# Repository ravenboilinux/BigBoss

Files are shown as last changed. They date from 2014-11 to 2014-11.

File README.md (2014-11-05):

BigBoss
=======
First regulated box mode 

Goals
=====
1. selectable wattage in .1 steps up 100W
2. handles max 100W between the atty ranges .5 ohms to 2 ohms
3. uses 2 18650 batteries
4. charges the batteries by USB
5. has LCD display
6. LCD displays
  * selected wattage to the nearest .1 Wattage
  * battery power remaining
    - using a battery icon, with 4 section.
  * voltage coming out the DC-DC convert to the nearest .01 V
  * atty resistance to the nearest .1 Ohms
7. selected wattage is saved when there is no power to device
8. two button for wattage selection(up/down)
9. master button for turn off the device
10. fire button 
11. has reverse polority protection

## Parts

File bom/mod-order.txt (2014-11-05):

Order list for C:/Users/Mike/Documents/eagle/120WMod/mod.sch
Exported from EAGLE with DesignLink

Quantity	Value	Package	Order code	Manufacturer	Manuf. Code	Availability	Price (from)	Description
1		C0805	68R0289		RC0805JR-1347KL	56682	0.0020	YAGEO - RC0805JR-1347KL - RESISTOR, THICK FILM, 47KOHM, 125mW, 5%
2	22pf	C0805	21T9850		MC0805N220J501CT	6996	0.0090	MULTICOMP - MC0805N220J501CT - CAPACITOR CERAMIC 22PF 500V, C0G, 5%, 0805
4	1uf	C0805	68R0289		RC0805JR-1347KL	56682	0.0020	YAGEO - RC0805JR-1347KL - RESISTOR, THICK FILM, 47KOHM, 125mW, 5%
1	5.6V	SMB	98H0775	ON SEMICONDUCTOR	MMBZ5232BLT1G	26495	0.017	ON SEMICONDUCTOR - MMBZ5232BLT1G - ZENER DIODE, 225mW, 5.6V, SOT-23
2	RESETTABLE_1210	1210	04H7797	RAYCHEM/POLYSWITCH	RGEF1000	42	0.337	TE CONNECTIVITY / RAYCHEM - RGEF1000 - FUSE, PTC RESET, 16V, 10A, RADIAL
1	MCP73811/2	SOT23-5L	27M0231		MCP73811T-420I/OT	4870	0.39	MICROCHIP - MCP73811T-420I/OT - IC, BATTERY CHARGER, 450mA, SOT23-5
1		1X01	unknown					
1	red	CHIPLED_0805	06R2522		C503B-RAS-CY0B0AA1	6148	0.094	CREE - C503B-RAS-CY0B0AA1 - LED, RED, T-1 3/4 (5MM), 12CD, 630NM
1	8.0MHz	CTS406	80P4001		CSTCE8M00G55Z-R0	430	0.306	MURATA - CSTCE8M00G55Z-R0 - RESONATOR, SMD, 8.0MHZ 
4	10k ohms	R0805	26R4046		CRCW080510K0FKEB	19543	0.019	VISHAY DALE - CRCW080510K0FKEB - RESISTOR, THICK FILM, 10KOHM, 125mW, 1%
2	220 ohms	R0805	59M6876		CRCW0805220RJNEA	6793	0.017	VISHAY DALE - CRCW0805220RJNEA - RESISTOR, THICK FILM, 220 OHM, 125mW, 5%
3	SPST_TACTILE_SW	6X3.5_TACTILE_SW	unknown					
1	MCP1702T-1802E/CB	SOT95P300X145-3N	84R5177		MCP1702T-1802E/CB	28	0.291	MICROCHIP - MCP1702T-1802E/CB - IC, LDO VOLT REG, 1.8V, 0.25A, SOT-23A-3
1	MCP4161-502E/SN	SOIC127P600X175-8N	77M2747		MCP4161-502E/SN	25	0.73	MICROCHIP - MCP4161-502E/SN - IC, DIG POT, 5kohm, 257STEP, Single, SOIC8
1	PIC16F877-04/L	PLCC127P1752X1752X457-44N	23C5092	MICROCHIP	PIC16F877-04/L	72	4.6	MICROCHIP - PIC16F877-04/L - MCU, 8BIT, PIC16, 4MHZ, PLCC-44
1	SI1317DL-T1-GE3	SOT65P210X110-3N	64T4051		SI1317DL-T1-GE3	1730	0.171	VISHAY SILICONIX - SI1317DL-T1-GE3 - MOSFET, P CH, W/D, 20V, 1.4A, SOT323
1	53261-14	53261-14	unknown					
1	53261-02	53261-02	unknown					
1	53398-10	53398-10	unknown	MOLEX	53398-1071

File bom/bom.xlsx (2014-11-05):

BOM: BigBoss
Assembly Part Number/Revision: BigBossA/2
Customer / Company Name: Michael Joye
Item # | Quantity per board | Manufacturer Part # | Do Not Install | Reference designators | Value (optional) | Size / Footprint (optional) | Part description/ specs (optional, but recommended) | Manfacturer (optional)
1 | 3 | C2012X5R0J336M125AC |  | C1,C2,C9 | 33UF | C0805 | CAP CER 33UF 6.3V 20% X5R 0805 | TDK Corporation
2 | 2 | CL21C220JCANNND |  | C3,C4 | 22PF | C0805 | CAP CER 22PF 100V 5% NP0 0805 | Samsung Electro-Mechanics America, Inc
3 | 3 | CL21C010CBANNNC |  | C5,C8 | 1PF | C0805 | CAP CER 1PF 50V NP0 0805 | Samsung Electro-Mechanics America, Inc
4 | 2 | CMPSH1-4 TR |  | D1,D3 | 40V 1.75A | SOT23 | DIODE SCHOTTKY 40V 1.75A SOT-23F | Central Semiconductor Corp
5 | 13 | ESR10EZPJ103 |  | R1,R2,R3,R5,R6,R9,R11,R12,R15,R17,R18,R19,R20,R10 | 10K Ohms | R0805 | RES 10K OHM .4W 5% 0805 SMD | Rohm Semiconductor
6 | 1 | 74HC595D,118 |  | IC1 | 8bit | 16-SOIC | IC SHIFT REGISTER 8BIT 16SOIC | NXP Semiconductors
7 | 1 | AP3216SGC |  | LED1 | 568nm | 1206 | 3.2X1.6MM GRN SMD LED | Kingbright
8 | 1 | ECS-80-16-28A-TR |  | Q3 | 8MHz | HC49/US | Crystals 8MHz 18pF 30ppm -40C +85C | ECS Inc
9 | 1 | PLT0805Z5000AST5 |  | R4 | 500 Ohms | R0805 | RES 500 OHM 1/4W 0.05% 0805 | Vishay Thin Film
10 | 1 | ESR10EZPF4R75 |  | R13 | 4.75K Ohms | R0805 | RES 4.75 OHM .4W 1% 0805 SMD | Rohm Semiconductor
11 | 1 | MCR10ERTF1001 |  | R16 | 1K Ohms | R0805 | RES 1K OHM 1/8W 1% 0805 SMD | Rohm Semiconductor
12 | 1 | MCP73213-A6SI/MF |  | U$2 | 4.2V | 10-VFDFN Exposed Pad | IC LI-ION/LI-POLY CTRLR 10-DFN | Microchip Technology
13 | 1 | MAX1683EUK+T |  | U$3 | IC REG SWITCHED CAP DBL SOT23-5 | SOT-753 | IC REG SWITCHED CAP DBL SOT23-5 | Maxim Integrated
14 | 1 | MCP1702T-5002E/CB |  | U$5 | IC REG LDO 5V 0.25A SOT23A-3 | SOT-23-3 | IC REG LDO 1.8V 0.2A SOT23A-3 | Microchip Technology
15 | 1 | MCP4161-502E/SN |  | U$7 | IC POT DGTL SNGL 5K SPI 8SOIC | 8-SOIC | IC POT DGTL SNGL 5K SPI 8SOIC | Microchip Technology
16 | 1 | PIC16F877-04/L |  | U$9 | IC MCU 8BIT 14KB FLASH 44PLCC | 44-LCC (J-Lead) | IC MCU 8BIT 14KB FLASH 44PLCC | Microchip Technology
17 | 1 | AD8628ARTZ-R2 |  | U1 | IC OPAMP ZRO-DRFT 2.5MHZ SOT23-5 | SC-74A, SOT-753 | IC OPAMP ZRO-DRFT 2.5MHZ SOT23-5 | Analog Devices Inc
18 | 1 | SI1317DL-T1-GE3 |  | U2 | MOSFET P-CH 20V 1.4A SC70 | SC-70, SOT-323 | MOSFET P-CH 20V 1.4A SC70 | Vishay Siliconix
19 | 1 | 22-23-2061 |  | X1 | CONN HEADER 6POS .100 VERT TIN | -- | CONN HEADER 6POS .100 VERT TIN | Molex Inc
 | 1 | MUSB-05-F-B-SM-A-TR |  | X2 | CONN RECEPT USB MINI B SMD R/A | -- | CONN RECEPT USB MINI B SMD R/A | Samtec Inc

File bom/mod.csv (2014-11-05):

Part | Value | Device | Package | Description | DESCRIPTION | FUSE | MF | MPN | OC_FARNELL | OC_NEWARK | PACKAGE | PROD_ID | SUPPLIER | VOLTS | VOUT
C1 | 33uf | C-USC0805 | C0805 | CAPACITOR, American symbol |  |  |  | RC0805JR-1347KL |  | 68R0289
C2 | 33uf | C-USC0805 | C0805 | CAPACITOR, American symbol |  |  |  | RC0805JR-1347KL |  | 68R0289
C3 | 22pf | C-USC0805 | C0805 | CAPACITOR, American symbol |  |  |  | MC0805N220J501CT |  | 21T9850
C4 | 22pf | C-USC0805 | C0805 | CAPACITOR, American symbol |  |  |  | MC0805N220J501CT |  | 21T9850
C5 | 1uf | C-USC0805 | C0805 | CAPACITOR, American symbol |  |  |  | RC0805JR-1347KL |  | 68R0289
C8 | 1uf | C-USC0805 | C0805 | CAPACITOR, American symbol |  |  |  | RC0805JR-1347KL |  | 68R0289
C9 | 33uf | C-USC0805 | C0805 | CAPACITOR, American symbol |  |  |  | RC0805JR-1347KL |  | 68R0289
D1 | BAS40 | BAS40 | SOT23 | Silicon Schottky Diodes |  |  |  |  |  |  |  |  |  | 5.6
D3 | BAS40 | BAS40 | SOT23 | Silicon Schottky Diodes |  |  |  |  |  |  |  |  |  | 5.6
FUSE1 | RESETTABLE_1210 | RESETTABLE_1210 | 1210 | resettable fuse |  |  | RAYCHEM/POLYSWITCH | RGEF1000 |  | 04H7797
FUSE2 | RESETTABLE_1210 | RESETTABLE_1210 | 1210 | resettable fuse |  |  | RAYCHEM/POLYSWITCH | RGEF1000 |  | 04H7797
IC1 | 74HC595D | 74HC595D | SO16 | 8-bit SHIFT REGISTER, output latch
LED1 | RED | LEDCHIPLED_1206 | CHIPLED_1206 | LED
LED2 | RED | LEDCHIPLED_1206 | CHIPLED_1206 | LED
PAD1 | DB4 | WIREPADSMD1,27-254 | SMD1,27-2,54 | Wire PAD connect wire on PCB
PAD3 | BATVSS | WIREPADSMD1,27-254 | SMD1,27-2,54 | Wire PAD connect wire on PCB
PAD5 | E | WIREPADSMD1,27-254 | SMD1,27-2,54 | Wire PAD connect wire on PCB
PAD6 | 510- | WIREPADSMD1,27-254 | SMD1,27-2,54 | Wire PAD connect wire on PCB
PAD7 | BATGDN | WIREPADSMD1,27-254 | SMD1,27-2,54 | Wire PAD connect wire on PCB
PAD8 | DB5 | WIREPADSMD1,27-254 | SMD1,27-2,54 | Wire PAD connect wire on PCB
PAD9 | RW | WIREPADSMD1,27-254 | SMD1,27-2,54 | Wire PAD connect wire on PCB
PAD10 | RS | WIREPADSMD1,27-254 | SMD1,27-2,54 | Wire PAD connect wire on PCB
PAD12 | DB6 | WIREPADSMD1,27-254 | SMD1,27-2,54 | Wire PAD connect wire on PCB
PAD13 | DB7 | WIREPADSMD1,27-254 | SMD1,27-2,54 | Wire PAD connect wire on PCB
PAD14 | FIRE+ | WIREPADSMD1,27-254 | SMD1,27-2,54 | Wire PAD connect wire on PCB
PAD15 | RAP5 | WIREPADSMD1,27-254 | SMD1,27-2,54 | Wire PAD connect wire on PCB
PAD16 | FIRE- | WIREPADSMD1,27-254 | SMD1,27-2,54 | Wire PAD connect wire on PCB
PAD17 | RAP10 | WIREPADSMD1,27-254 | SMD1,27-2,54 | Wire PAD connect wire on PCB
PAD18 | RAP3 | WIREPADSMD1,27-254 | SMD1,27-2,54 | Wire PAD connect wire on PCB
PAD19 | RAP2 | WIREPADSMD1,27-254 | SMD1,27-2,54 | Wire PAD connect wire on PCB
PAD20 | RAP9 | WIREPADSMD1,27-254 | SMD1,27-2,54 | Wire PAD connect wire on PCB
PAD21 | UP+ | WIREPADSMD1,27-254 | SMD1,27-2,54 | Wire PAD connect wire on PCB
PAD22 | DOWN+ | WIREPADSMD1,27-254 | SMD1,27-2,54 | Wire PAD connect wire on PCB
PAD24 | LEDV0 | WIREPADSMD1,27-254 | SMD1,27-2,54 | Wire PAD connect wire on PCB
PAD25 | LCD+ | WIREPADSMD1,27-254 | SMD1,27-2,54 | Wire PAD connect wire on PCB
PAD26 | LCDGND | WIREPADSMD1,27-254 | SMD1,27-2,54 | Wire PAD connect wire on PCB
PAD27 | UP- | WIREPADSMD1,27-254 | SMD1,27-2,54 | Wire PAD connect wire on PCB
PAD28 | DOWN- | WIREPADSMD1,27-254 | SMD1,27-2,54 | Wire PAD connect wire on PCB
Q3 | CSM-4A-SMD | CSM-4A-SMD | HC49/US
R1 | 10k ohms | R-US_R0805 | R0805 | RESISTOR, American symbol |  |  |  | CRCW080510K0FKEB |  | 26R4046
R2 | 10k ohms | R-US_R0805 | R0805 | RESISTOR, American symbol |  |  |  | CRCW080510K0FKEB |  | 26R4046
R3 | 10k ohms | R-US_R0805 | R0805 | RESISTOR, American symbol |  |  |  | CRCW0805220RJNEA |  | 59M6876
R4 | .5 ohms | R-US_R0805 | R0805 | RESISTOR, American symbol |  |  |  | CRCW080510K0FKEB |  | 26R4046
R5 | 10k ohms | R-US_R0805 | R0805 | RESISTOR, American symbol |  |  |  | CRCW080510K0FKEB |  | 26R4046
R6 | 10k ohms | R-US_R0805 | R0805 | RESISTOR, American symbol |  |  |  | CRCW080510K0FKEB |  | 26R4046
R7 | 220 ohms | R-US_R0805 | R0805 | RESISTOR, American symbol |  |  |  | CRCW0805220RJNEA |  | 59M6876
R8 | 220 ohms | R-US_R0805 | R0805 | RESISTOR, American symbol |  |  |  | CRCW0805220RJNEA |  | 59M6876
R9 | 10k ohms | R-US_R0805 | R0805 | RESISTOR, American symbol |  |  |  | CRCW080510K0FKEB |  | 26R4046
R10 | 220 ohms | R-US_R0805 | R0805 | RESISTOR, American symbol |  |  |  | CRCW0805220RJNEA |  | 59M6876
R11 | 10k ohms | R-US_R0805 | R0805 | RESISTOR, American symbol |  |  |  | CRCW080510K0FKEB |  | 26R4046
R12 | 10k ohms | R-US_R0805 | R0805 | RESISTOR, American symbol |  |  |  | CRCW080510K0FKEB |  | 26R4046
R13 | 4.8k Ohms | R-US_R0805 | R0805 | RESISTOR, American symbol |  |  |  | CRCW080510K0FKEB |  | 26R4046
R15 | 10k ohms | R-US_R0805 | R0805 | RESISTOR, American symbol |  |  |  | CRCW080510K0FKEB |  | 26R4046
R16 | 1.5k ohms | R-US_R0805 | R0805 | RESISTOR, American symbol |  |  |  | CRCW080510K0FKEB |  | 26R4046
R17 | 10k ohms | R-US_R0805 | R0805 | RESISTOR, American symbol |  |  |  | CRCW080510K0FKEB |  | 26R4046
R18 | 10k ohms | R-US_R0805 | R0805 | RESISTOR, American symbol |  |  |  | CRCW080510K0FKEB |  | 26R4046
R19 | 10k ohms | R-US_R0805 | R0805 | RESISTOR, American symbol |  |  |  | CRCW080510K0FKEB |  | 26R4046
R20 | 10k ohms | R-US_R0805 | R0805 | RESISTOR, American symbol |  |  |  | CRCW080510K0FKEB |  | 26R4046
U$2 | MCP73213-MF | MCP73213-MF | 10-DFN
U$3 | MAX1683-5-SOT23 | MAX1683-5-SOT23 | SOT23-1
U$5 | MCP1702T-1802E/CB | MCP1702T-1802E/CB | SOT95P300X145-3N | Low Quiescent Current LDO Regulator | LDO VOLT REG |  |  | MCP1702T-1802E/CB | 1331488 | 84R5177 | SOT-3 |  | Microchip |  | 5V
U$7 | MCP4161-502E/SN | MCP4161-502E/SN | SOIC127P600X175-8N | Digital POT |  |  |  | MCP4161-502E/SN | 1840839 | 77M2747 | SOIC-8 |  | Microchip
U$9 | PIC16F877-04/L | PIC16F877-04/L | PLCC127P1752X1752X457-44N | 8-Bit CMOS FLASH Microcontrollers |  |  | MICROCHIP | PIC16F877-04/L | 9761330 | 23C5092 | PLCC-44 |  | Microchip
U1 | AD8628ARTZ-REEL7 | AD8628ARTZ-REEL7 | SOT95P290X145-5N | Zero-Drift, Single-Supply, RRIO Op Amp |  |  |  | AD8628ARTZ-REEL7 | unknown | 59K6995 | SOT-23-5 |  | Analog Devices
U2 | SI1317DL-T1-GE3 | SI1317DL-T1-GE3 | SOT65P210X110-3N | P-Channel 20 V (D-S) MOSFET |  |  |  | SI1317DL-T1-GE3 | 2056676 | 64T4051 | SOT-323-3 |  | VISHAY SILICONIX
X1 | ICPS | 22-23-2061 | 22-23-2061 | .100 (2.54mm) Center Header - 6 Pin" |  |  | MOLEX | 22-23-2061 | 1462922 | 27C1933
X2 | USB-MICROB | USB-MICROB | USB-MICROB | USB Connectors |  |  |  |  |  |  |  | CONN-09505

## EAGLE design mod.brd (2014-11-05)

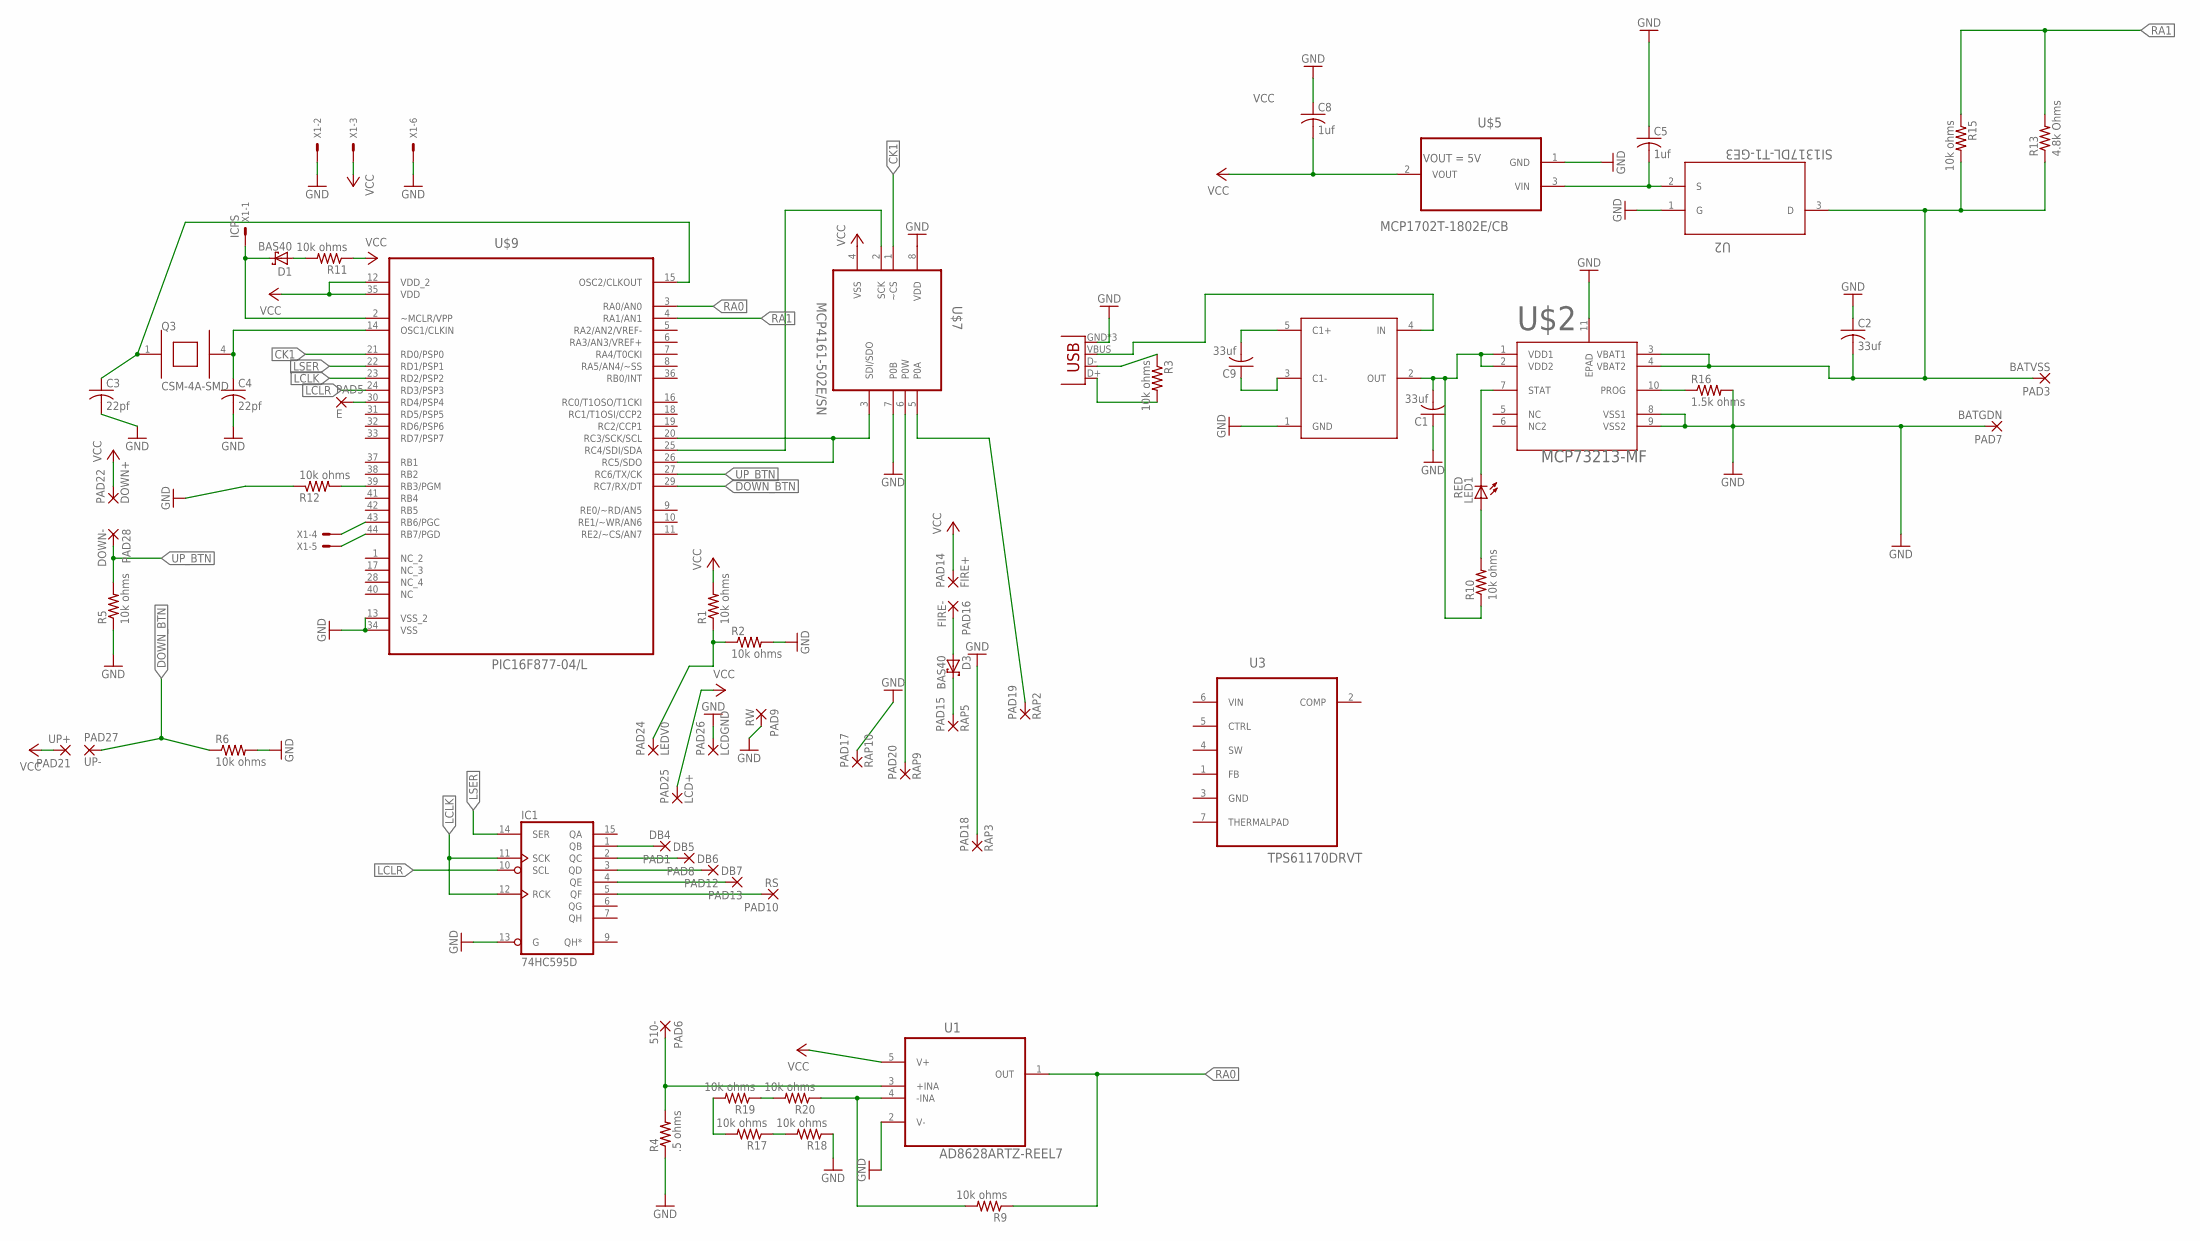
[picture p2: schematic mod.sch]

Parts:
C1, C2, C9: 33uf; C0805; MPN RC0805JR-1347KL
C3, C4: 22pf; C0805; MPN MC0805N220J501CT
C5, C8: 1uf; C0805; MPN RC0805JR-1347KL
D1, D3: BAS40; SOT23
IC1: 74HC595D; SO16
LED1: RED; CHIPLED_1206
PAD1: DB4; SMD1,27-2,54
PAD3: BATVSS; SMD1,27-2,54
PAD5: E; SMD1,27-2,54
PAD6: 510-; SMD1,27-2,54
PAD7: BATGDN; SMD1,27-2,54
PAD8: DB5; SMD1,27-2,54
PAD9: RW; SMD1,27-2,54
PAD10: RS; SMD1,27-2,54
PAD12: DB6; SMD1,27-2,54
PAD13: DB7; SMD1,27-2,54
PAD14: FIRE+; SMD1,27-2,54
PAD15: RAP5; SMD1,27-2,54
PAD16: FIRE-; SMD1,27-2,54
PAD17: RAP10; SMD1,27-2,54
PAD18: RAP3; SMD1,27-2,54
PAD19: RAP2; SMD1,27-2,54
PAD20: RAP9; SMD1,27-2,54
PAD21: UP+; SMD1,27-2,54
PAD22: DOWN+; SMD1,27-2,54
PAD24: LEDV0; SMD1,27-2,54
PAD25: LCD+; SMD1,27-2,54
PAD26: LCDGND; SMD1,27-2,54
PAD27: UP-; SMD1,27-2,54
PAD28: DOWN-; SMD1,27-2,54
Q3: CSM-4A-SMD; HC49/US
R1, R2, R5, R6, R9, R11, R12, R15, R17, R18, R19, R20: 10k ohms; R0805; MPN CRCW080510K0FKEB
R3, R10: 10k ohms; R0805; MPN CRCW0805220RJNEA
R4: .5 ohms; R0805; MPN CRCW080510K0FKEB
R13: 4.8k Ohms; R0805; MPN CRCW080510K0FKEB
R16: 1.5k ohms; R0805; MPN CRCW080510K0FKEB
U1: AD8628ARTZ-REEL7; SOT95P290X145-5N
U2: SI1317DL-T1-GE3; SOT65P210X110-3N
U3: TPS61170DRVT; SON65P210X210X80-7N
U$2: MCP73213-MF; 10-DFN
U$3: MAX1683-5-SOT23; SOT23-1
U$5: MCP1702T-1802E/CB; SOT95P300X145-3N
U$7: MCP4161-502E/SN; SOIC127P600X175-8N
U$9: PIC16F877-04/L; PLCC127P1752X1752X457-44N
X1: ICPS; 22-23-2061
X2: USB-MICROB

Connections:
AD_DC: C2.2, PAD3.1, R13.1, R15.2, U2.3 (D), U$2.3 (VBAT1), U$2.4 (VBAT2)
CK1: U$7.1 (~CS), U$9.21 (RD0/PSP0)
CLKOUT: C3.1, Q3.1, U$9.15 (OSC2/CLKOUT)
DOWN_BTN: PAD27.1, R6.1, U$9.29 (RC7/RX/DT)
GND: C1.1, C2.1, C3.2, C4.2, C5.1, C8.1, IC1.8 (GND), IC1.13 (G), PAD7.1, PAD9.1, PAD17.1, PAD18.1, PAD26.1, R2.2, R4.1, R5.1, R6.2, R12.1, R16.2, R18.1, U1.2 (V-), U2.1 (G), U$2.8 (VSS1), U$2.9 (VSS2), U$2.11 (EPAD), U$3.1 (GND), U$5.1 (GND), U$7.7 (P0B), U$7.8 (VDD), U$9.13 (VSS_2), U$9.34 (VSS), X1.2, X1.6, X2.GND, X2.MT1 (GND), X2.MT2 (GND)
LCLK: IC1.11 (SCK), IC1.12 (RCK), U$9.23 (RD2/PSP2)
LCLR: IC1.10 (SCL), U$9.24 (RD3/PSP3)
LSER: IC1.14 (SER), U$9.22 (RD1/PSP1)
unnamed: C5.2, U2.2 (S), U$5.3 (VIN)
unnamed: D3.1 (A), PAD16.1
unnamed: C4.1, Q3.4 (2), U$9.14 (OSC1/CLKIN)
unnamed: D3.3 (C), PAD15.1
unnamed: R3.1, X2.D-
unnamed: PAD20.1, U$7.6 (P0W)
unnamed: PAD19.1, U$7.5 (P0A)
unnamed: R3.2, X2.D+
unnamed: PAD6.1, R4.2, U1.3 (+INA)
unnamed: C9.2, U$3.5 (C1+)
unnamed: U$7.2 (SCK), U$9.25 (RC4/SDI/SDA)
unnamed: U$7.3 (SDI/SDO), U$9.20 (RC3/SCK/SCL), U$9.26 (RC5/SDO)
unnamed: R9.2, R20.1, U1.4 (-INA)
unnamed: IC1.1 (QB), PAD1.1
unnamed: D1.1 (A), R11.2
unnamed: D1.3 (C), U$9.2 (~MCLR/VPP), X1.1
unnamed: IC1.2 (QC), PAD8.1
unnamed: U$9.43 (RB6/PGC), X1.4
unnamed: U$9.44 (RB7/PGD), X1.5
unnamed: IC1.3 (QD), PAD12.1
unnamed: R12.2, U$9.39 (RB3/PGM)
unnamed: IC1.4 (QE), PAD13.1
unnamed: IC1.5 (QF), PAD10.1
unnamed: PAD5.1, U$9.30 (RD4/PSP4)
unnamed: U$3.4 (IN), X2.VBUS
unnamed: C9.1, U$3.3 (C1-)
unnamed: C1.2, R10.1, U$2.1 (VDD1), U$2.2 (VDD2), U$3.2 (OUT)
unnamed: LED1.A, R10.2
unnamed: LED1.C, U$2.7 (STAT)
unnamed: R16.1, U$2.10 (PROG)
unnamed: R19.1, R20.2
unnamed: R17.2, R19.2
unnamed: R17.1, R18.2
RA0: R9.1, U1.1 (OUT), U$9.3 (RA0/AN0)
RA1: R13.2, R15.1, U$9.4 (RA1/AN1)
UP_BTN: PAD28.1, R5.2, U$9.27 (RC6/TX/CK)
VCC: C8.2, IC1.16 (VCC), PAD14.1, PAD21.1, PAD22.1, PAD25.1, R1.2, R11.1, U1.5 (V+), U$5.2 (VOUT), U$7.4 (VSS), U$9.12 (VDD_2), U$9.35 (VDD), X1.3
VIN: U3.6 (VIN)
VO: PAD24.1, R1.1, R2.1

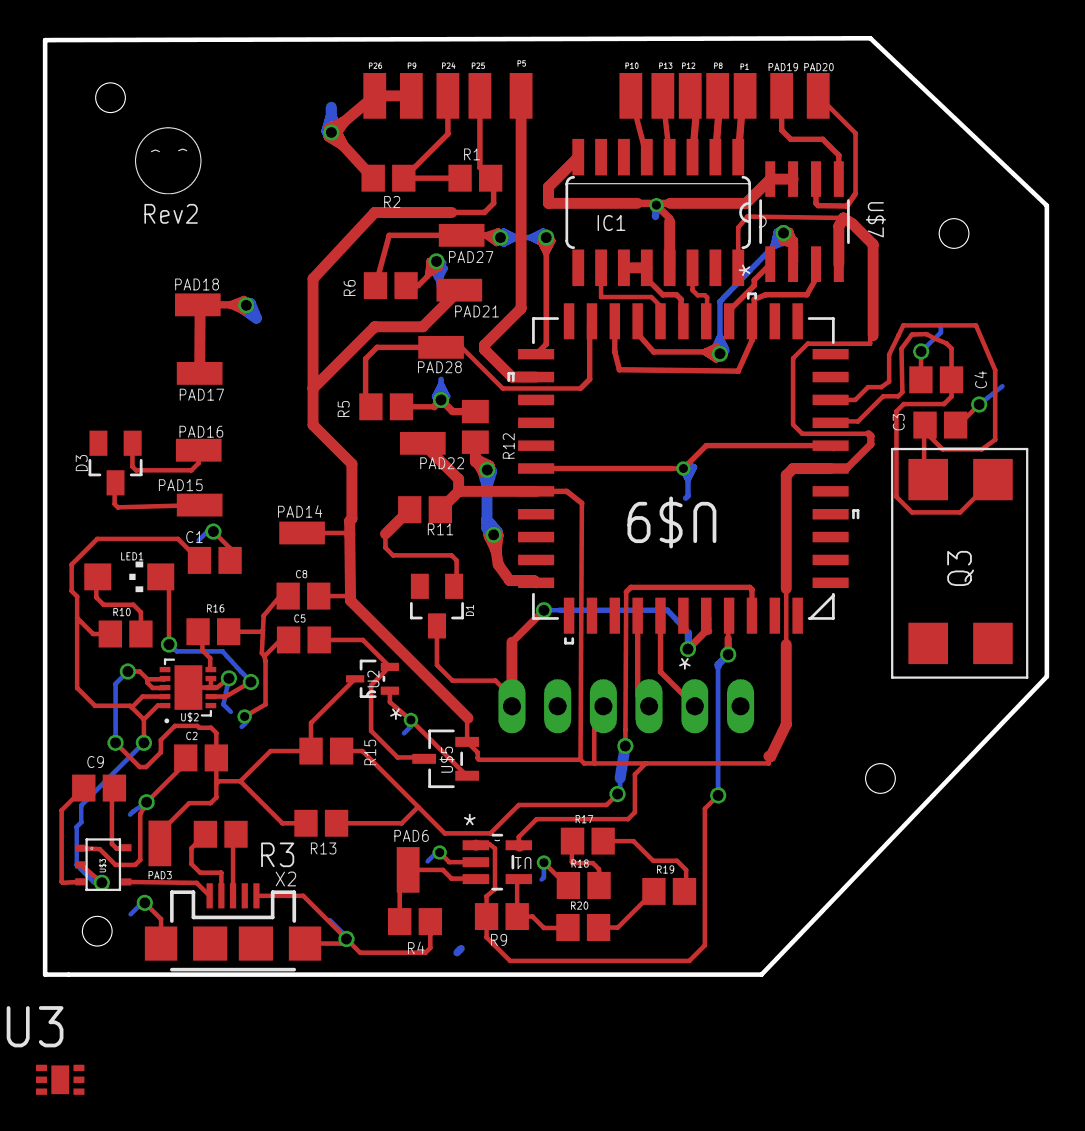
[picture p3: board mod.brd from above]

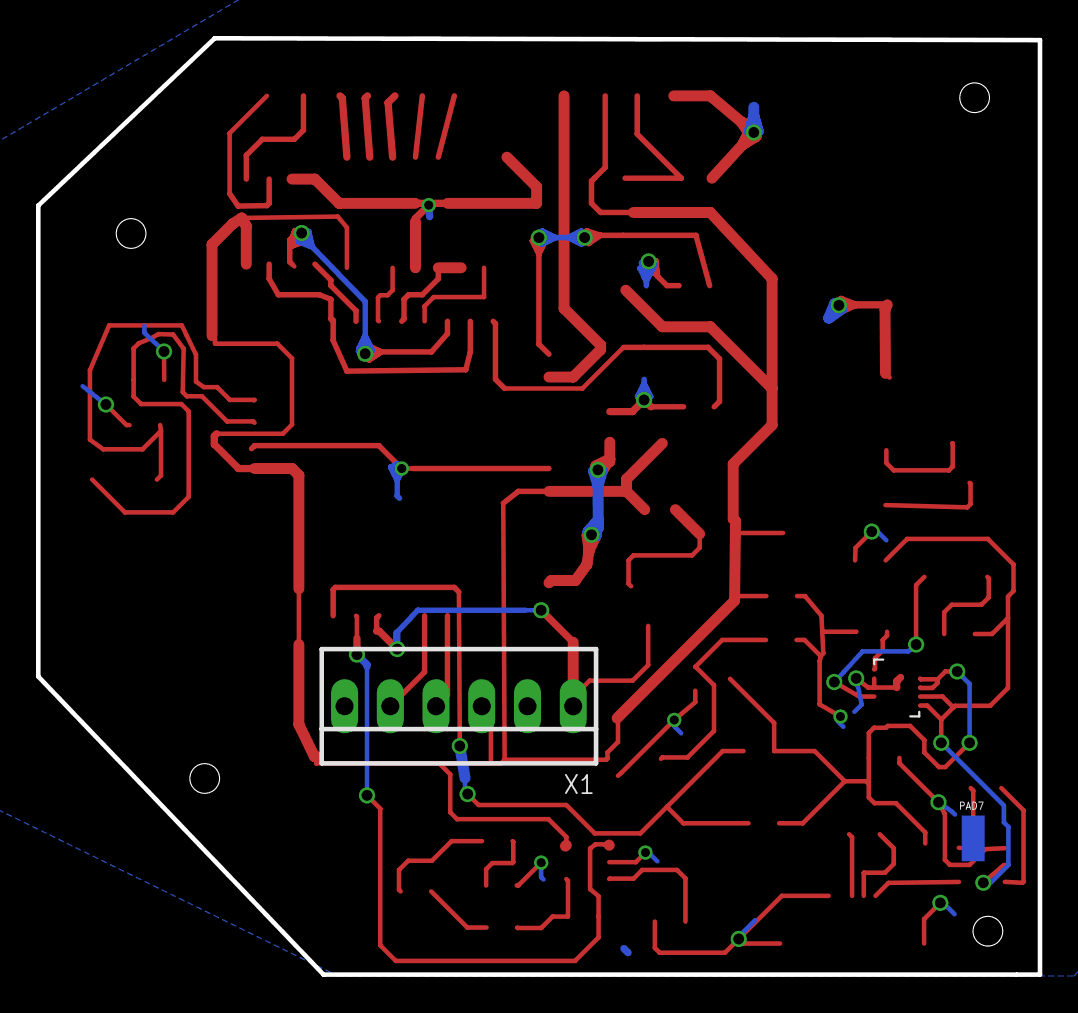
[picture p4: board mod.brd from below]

Board: 2 copper layers, 55.7 x 52.0 mm, 64 parts (2 on the bottom side), 46 nets.

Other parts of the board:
U$1: WINKLOGO

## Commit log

2014-11-05 Eagle Project
    [bom.xlsx, mod.brd, mod.csv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]
2014-11-13 datasheets for ICs
    using the MAX15046-MAX15046B-220655 buck converter
    datasheet for ICs
    Pic MCU Datasheets
    datasheet
2014-11-13 Product Docs
    [powerSetting.xlsx]

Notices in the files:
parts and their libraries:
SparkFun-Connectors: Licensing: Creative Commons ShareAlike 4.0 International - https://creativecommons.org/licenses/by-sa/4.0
